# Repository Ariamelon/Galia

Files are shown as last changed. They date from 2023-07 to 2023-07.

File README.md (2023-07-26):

# Galia
USB-C breakout board.

## Disclaimer
This board is licensed under CC BY 4.0.
## Key Features
* Full ESD protection for data lines and VBUS.
* Two buttons on board that can be snapped off.
* Two M3 mounting holes, one of which is connected to ground for earthing the chassis.
* 6-pin JST SH connector capable of handling up to 3A power.

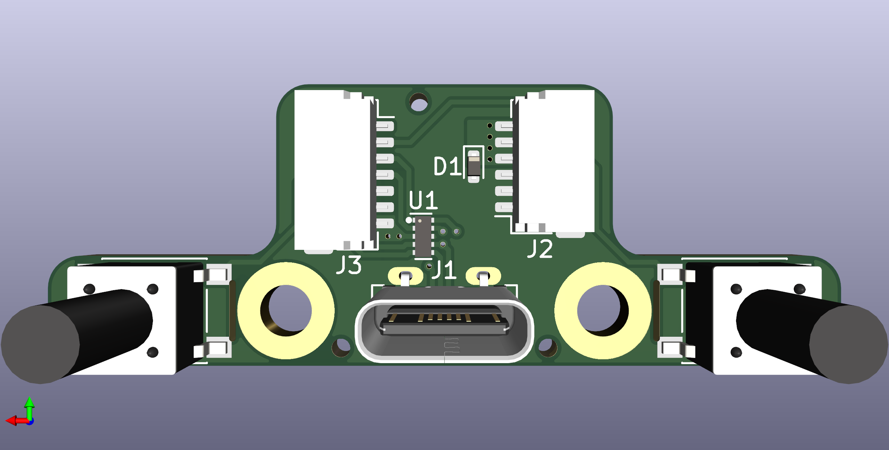
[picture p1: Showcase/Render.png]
Render


## Changelog
* 26/07/2023: Fixed position of button and mounting holes. Added JLC tooling holes.
* 25/07/2023: Changed 8 pin JST SH connector to 6 pin. Changed orientation of SH connectors for easier routing of wires. Added Ariamelon logo. Added PCB cutouts to allow for buttons to be snapped off.
* 21/07/2023: Changed 20 pin FFC to 7 pin and 8 pin JST SH connector. Fixed orientation.
* 18/07/2023: Changed JST connector back to 20 pin FFC. Centered connector.
* 17/07/2023: Changed 20 pin FFC connector to 14 pin JST SH connector. Repositioned components.
* 16/07/2023: Changed PTS645 LCSC part number.
* 14/07/2023: Initial public upload of V1.0.

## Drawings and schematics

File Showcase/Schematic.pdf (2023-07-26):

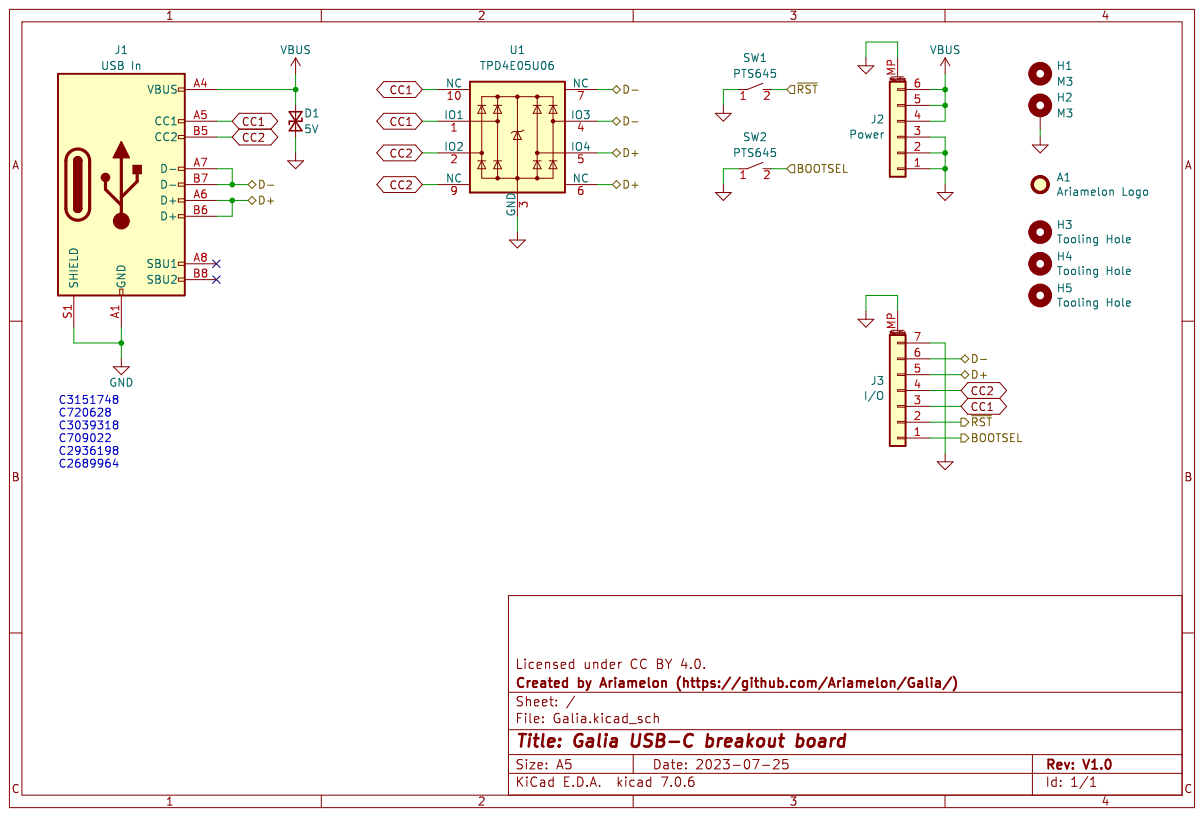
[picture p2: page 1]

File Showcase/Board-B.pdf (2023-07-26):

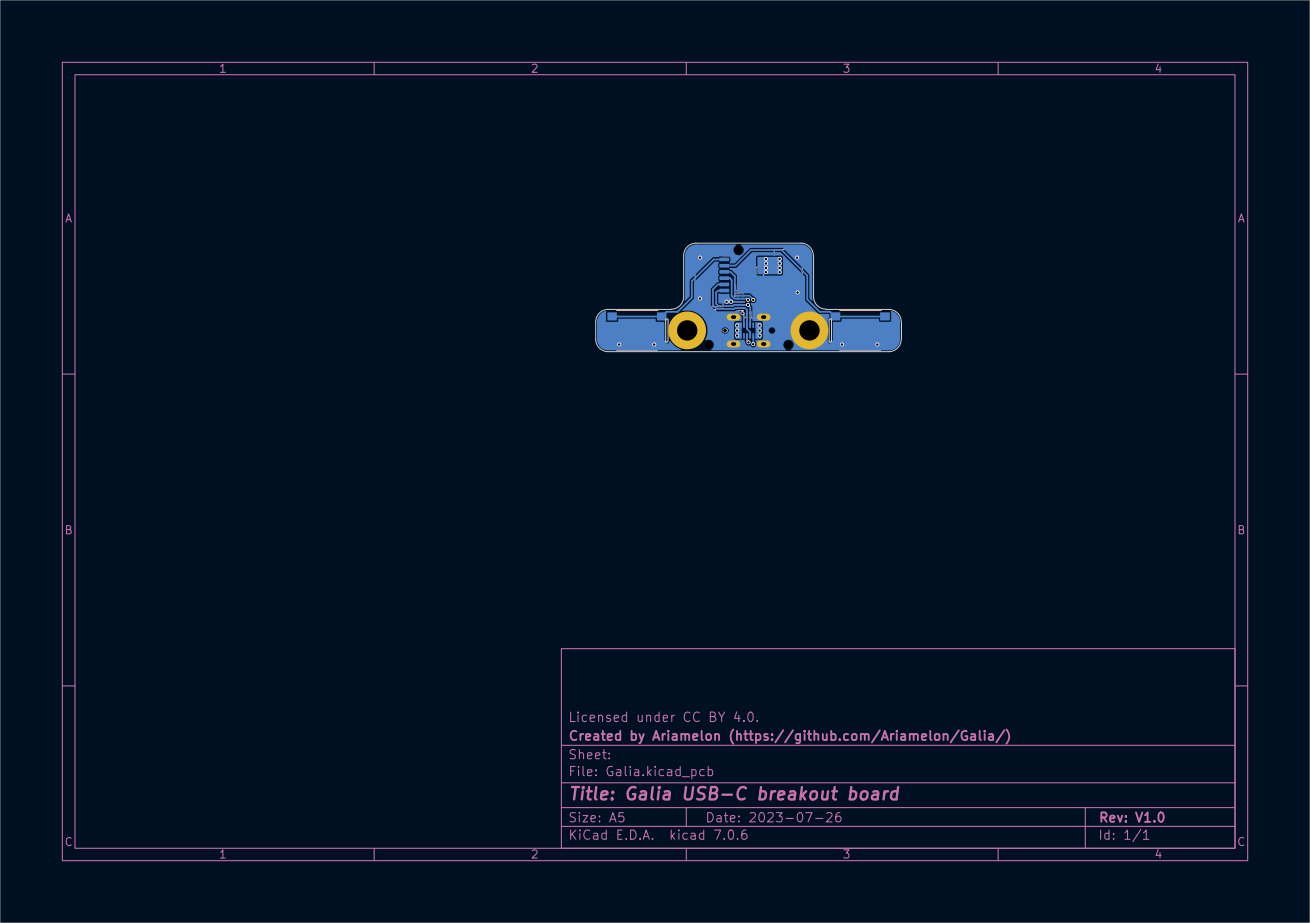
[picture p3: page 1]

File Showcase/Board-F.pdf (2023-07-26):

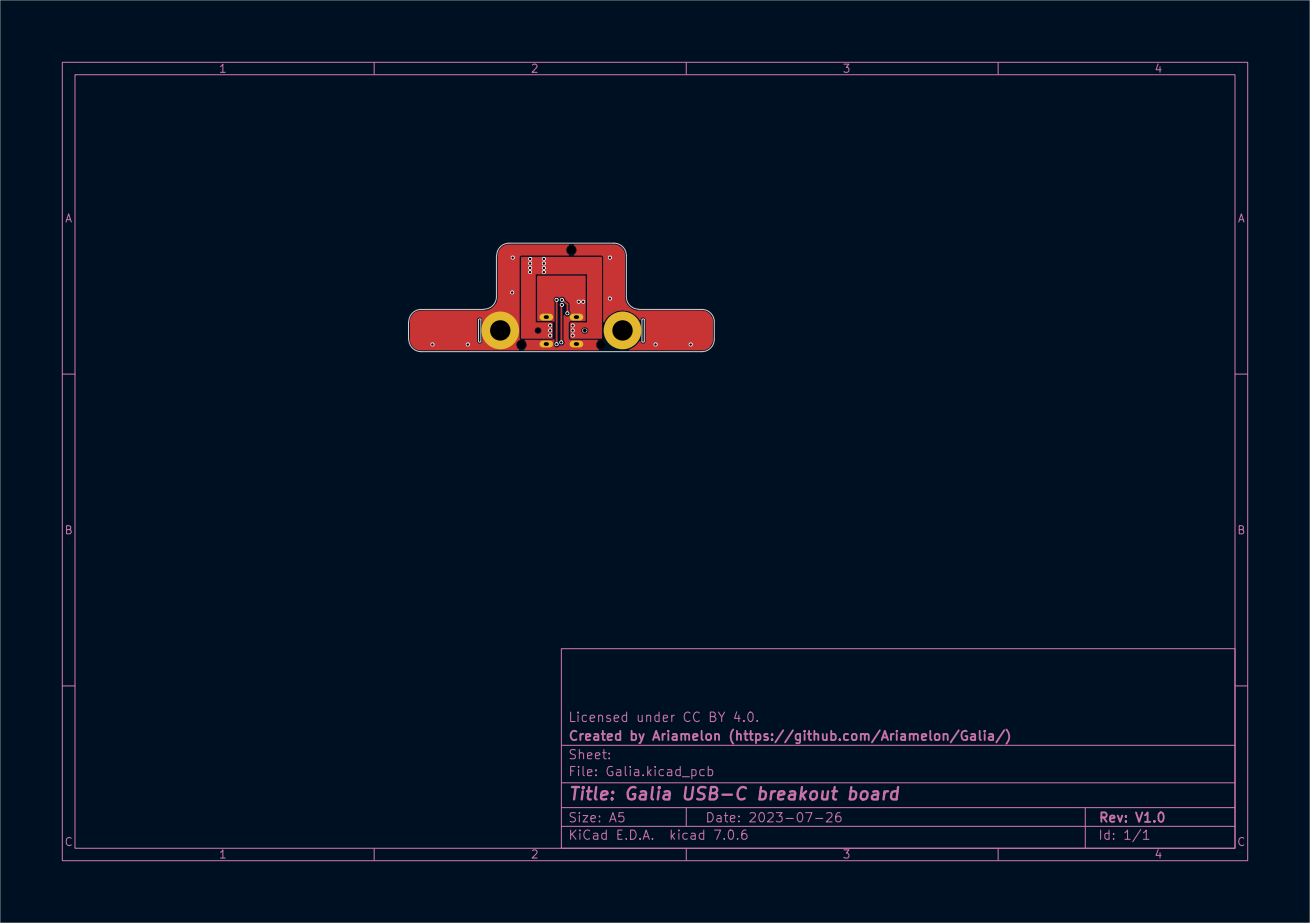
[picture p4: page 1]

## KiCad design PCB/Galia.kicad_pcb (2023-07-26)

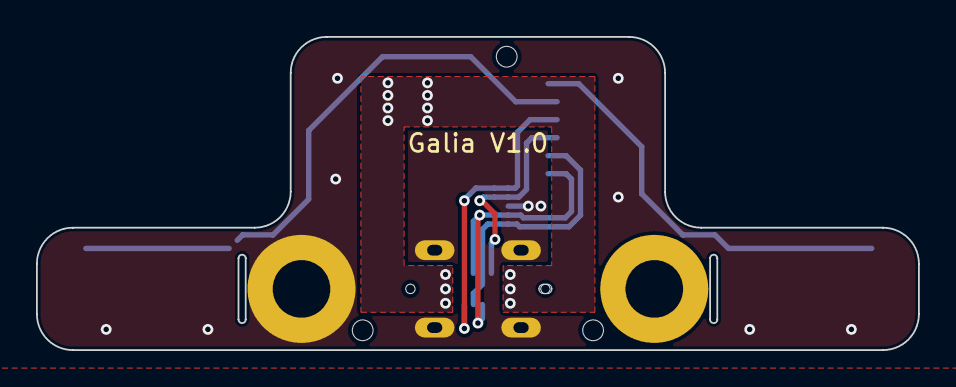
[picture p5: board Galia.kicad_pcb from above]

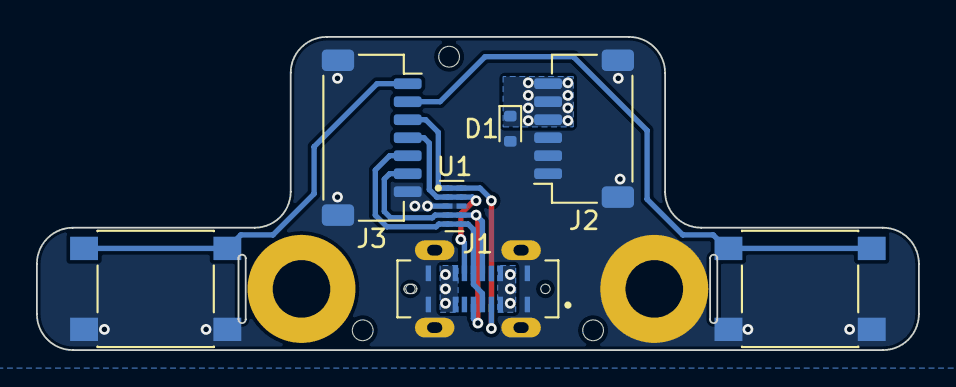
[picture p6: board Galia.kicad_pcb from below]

Board: 2 copper layers, 49.0 x 17.4 mm, 13 parts (9 on the bottom side), 8 nets.

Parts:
A1: Ariamelon Logo; Ariamelon_Logo_Mask
D1: 5V; D_SOD-523
H1, H2: M3; MountingHole_3.2mm_M3_Pad
H3, H4, H5: Tooling Hole; JLC Tooling Hole
J1: USB In; CON-USB4120-03-C-REVA
J2: Power; JST_SH_SM06B-SRSS-TB_1x06-1MP_P1.00mm_Horizontal
J3: I/O; JST_SH_SM07B-SRSS-TB_1x07-1MP_P1.00mm_Horizontal
SW1, SW2: PTS645; SW_SPST_PTS645
U1: TPD4E05U06; USON-10_2.5x1.0mm_P0.5mm

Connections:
/BOOTSEL: J3.1, SW2.2 (B)
/D+: J1.A6 (D+), J1.B6 (D+), J3.5, U1.5 (IO4), U1.6 (NC)
/D-: J1.A7 (D-), J1.B7 (D-), J3.6, U1.4 (IO3), U1.7 (NC)
/~RST: J3.2, SW1.2 (B)
CC1: J1.A5 (CC1), J3.3, U1.1 (IO1), U1.10 (NC)
CC2: J1.B5 (CC2), J3.4, U1.2 (IO2), U1.9 (NC)
GND: D1.2 (A), H2.1, J1.A1 (GND), J1.A12 (GND), J1.B1 (GND), J1.B12 (GND), J1.S1 (SHIELD), J2.1, J2.2, J2.3, J2.MP (MountPin), J3.7, J3.MP (MountPin), SW1.1 (A), SW2.1 (A), U1.3 (GND), U1.8 (GND)
VBUS: D1.1 (K), J1.A4 (VBUS), J1.A9 (VBUS), J1.B4 (VBUS), J1.B9 (VBUS), J2.4, J2.5, J2.6

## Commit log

2023-07-14 Changed PTS645 LCSC part number
    [Galia-CuBottom.gbr, Galia-CuTop.gbr, Galia-EdgeCuts.gbr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]
2023-07-17 17/07/2023 update
    Changed 20 pin FFC connector to 14 pin JST SH connector. Repositioned components.
    [Galia-CuBottom.gbr, Galia-CuTop.gbr, Galia-EdgeCuts.gbr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]
2023-07-18 18/07/2023 update.
    Changed JST connector back to 20 pin FFC. Centered connector.
    [Galia-CuBottom.gbr, Galia-CuTop.gbr, Galia-EdgeCuts.gbr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]
2023-07-18 Added LCSC part number.
    [Galia-CuBottom.gbr, Galia-CuTop.gbr, Galia-EdgeCuts.gbr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]
2023-07-21 21/07/2023 update.
    Changed 20 pin FFC to 7 pin and 8 pin JST SH connector. Fixed orientation.
    [Galia-CuBottom.gbr, Galia-CuTop.gbr, Galia-EdgeCuts.gbr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]
2023-07-25 25/07/2023 update
    Changed 8 pin JST SH connector to 6 pin. Changed orientation of SH connectors for easier routing of wires. Added Ariamelon logo. Added PCB cutouts to allow for buttons to be snapped off.
    [Galia-CuBottom.gbr, Galia-CuTop.gbr, Galia-EdgeCuts.gbr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]
2023-07-26 26/07/2023 update
    Fixed position of button and mounting holes. Added JLC tooling holes.
    [Galia-CuBottom.gbr, Galia-CuTop.gbr, Galia-EdgeCuts.gbr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]
